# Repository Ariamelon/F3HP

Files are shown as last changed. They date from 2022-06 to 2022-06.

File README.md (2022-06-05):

# F3HP
A compact, class A amplifier with a schematic from [this](https://www.diyaudio.com/community/threads/3-transistor-hp-amplifier-with-low-dist.359267) thread.
This design uses mostly SMT components with some THT. It is designed to fit in [this](https://item.taobao.com/item.htm?id=543297256145) case. The 3D model and dimensions are included with the design files.

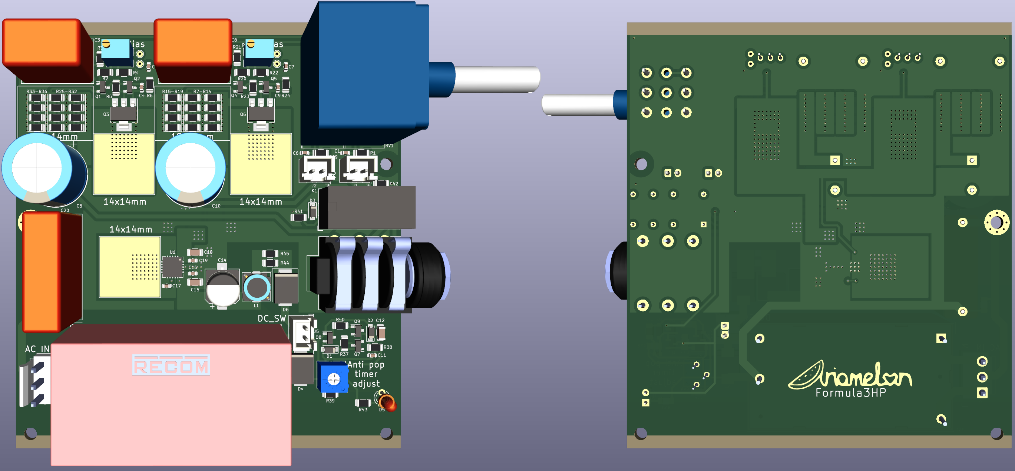
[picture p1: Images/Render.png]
Render

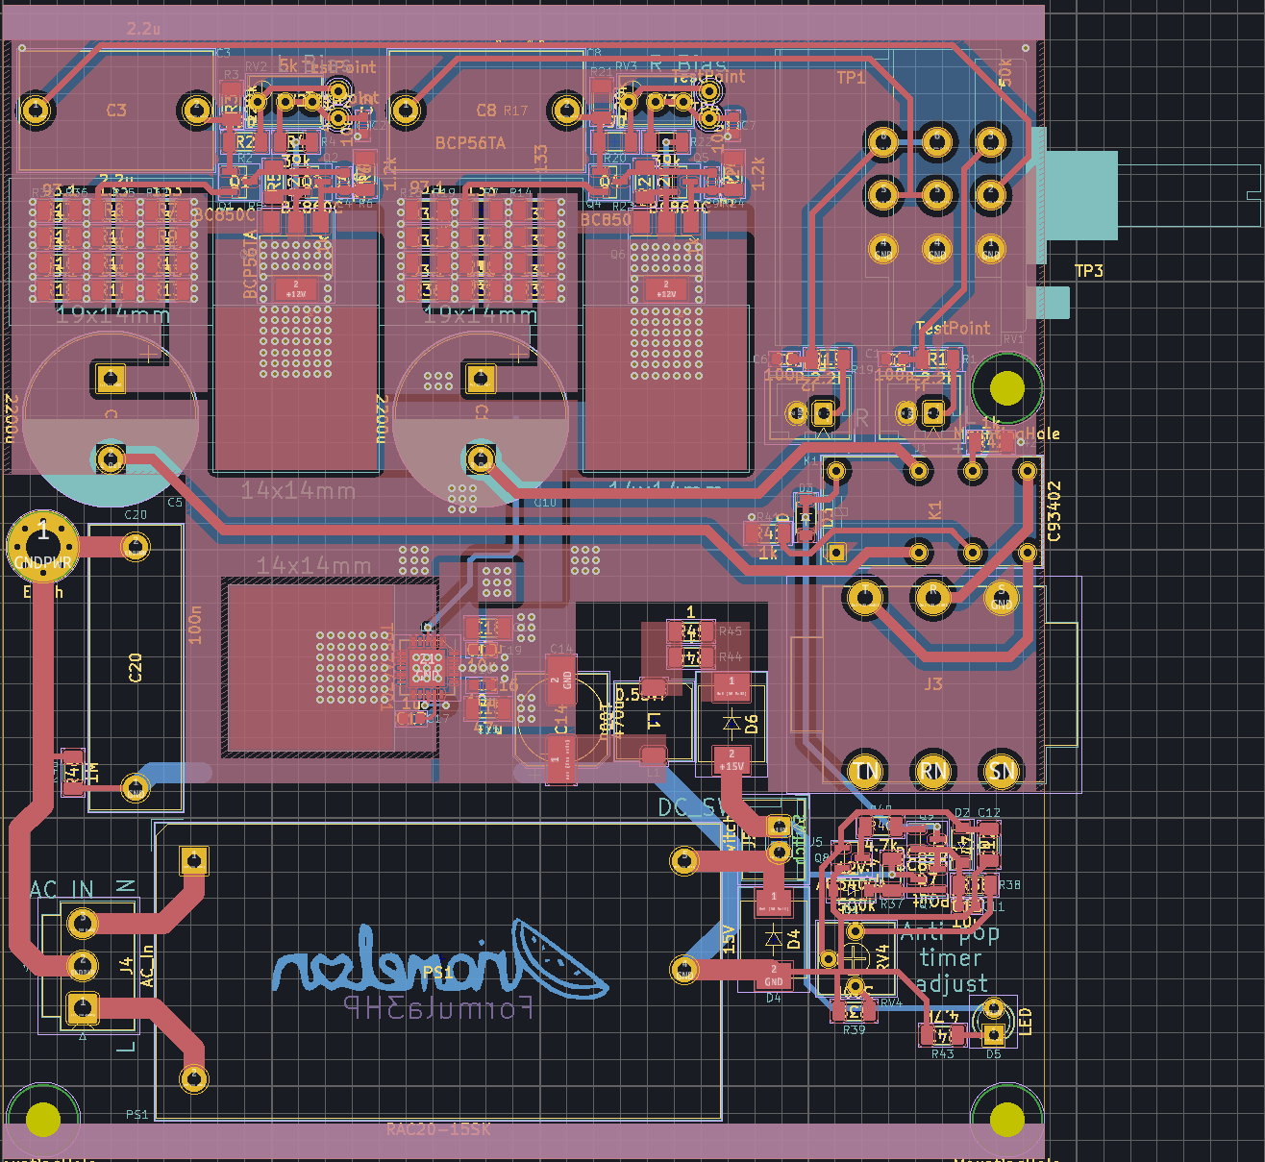
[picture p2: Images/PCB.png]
PCB

Schematic

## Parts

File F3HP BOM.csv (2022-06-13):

Qty | Reference(s) | Value | LCSC part number | Part number
2 | C1, C6 | 100p | C343033 | C1608NP01H101JT000N
5 | C2, C7, C11, C16, C19 | 10u | C2922482 | CL10A106MA8NRNC
2 | C3, C8 | 2.2u | C128507 | ECWFD2W225J
2 | C4, C9 | 330p | C343002 | C1608NP01H331JT000N
2 | C5, C10 | 2200u | C278533 | EEUFR1E222S
3 | C12, C15, C18 | 47u | C76659 | C3216X5R1E476MTJ00E
1 | C14 | 470u | C193277 | EEEFT1E471GP
1 | C17 | 1u | C15849 | CL10A105KB8NNNC
1 | C20 | 100n | C2926846 | PHE820ED6100MR06L2
1 | D1 | 12V | C550177 | BZT52-B12X
2 | D2, D3 | D | C81598 | 1N4148W
1 | D4 | 15V | C135138 | SMCJ15A-13-F
1 | D5 | LED | C2927624 | 204-10SUGC/S400-A5
1 | D6 | 0.55Vf | C134460 | B520C-13-F
1 | J1 | L_In | C158012 | B2B-XH-A
1 | J2 | R_In | C158012 | B2B-XH-A
1 | J3 | HPOut | C368502 | NMJ6HCD2
1 | J4 | AC_In | C160316 | B3P-VH(LF)(SN)
1 | J5 | Switch | C158012 | B2B-XH-A
1 | K1 | C93402 | C128021 | C93402
1 | L1 | 100u | C2045491 | SPM7054VT-101M-D
1 | PS1 | RAC20-15SK | N/A | RAC20-15SK
3 | Q1, Q4, Q7 | BC850C | C549507 | BC850C
3 | Q2, Q5, Q9 | BC860C | C549546 | BC860C
2 | Q3, Q6 | BCP56TA | C177012 | BCP56TA
1 | Q8 | AO3400A | C20917 | AO3400A
2 | R1, R19 | 2.2k |  | RT1206BRD072K2L
4 | R2, R20, R38, R39 | 392k |  | RT1206BRD07392KL
2 | R3, R21 | 120k | C136888 | RT1206BRD07120KL
2 | R4, R22 | 39.2k |  | RT1206DRD0739K2L
4 | R5, R23, R41, R42 | 1k | C706405 | RT1206BRD071KL
2 | R6, R24 | 1.4k | C870504 | RT1206BRD071K4L
16 | R7, R8, R9, R10, R11, R12, R13, R14, R25, R26, R27, R28, R29, R30, R31, R32 | 133 |  | RT1206DRD07133RL
8 | R15, R16, R17, R18, R33, R34, R35, R36 | 100 |  | RT1206DRD07100RL
3 | R37, R40, R43 | 4.7k | C706416 | RT1206BRD074K64L
2 | R44, R45 | 4.99 | C326584 | RT1206BRD074R99L
1 | R46 | 1M | C375528 | RT1206FRE071ML
1 | RV1 | 50k | C470507 | RK27112A00AK
2 | RV2, RV3 | 10k | C780232 | 3266W-1-104LF
1 | RV4 | 500k | C125021 | 3362P-1-504
1 | U1 | TPS7A4701 | C68214 | TPS7A4701
Additional
1 |  | IEC socket | N/A | DD11.0111.1111
1 |  | Fuse holder | N/A | 4301.1405
1 |  | Power switch | C1788492 | 100SP1T1B1M1QEH
1 |  | JST VH plug | C157899 | VHR-3N
3 |  | JST VH pins | C160349 | SVH-21T-P1.1
3 |  | JST XH plug | C144401 | XHP-2
6 |  | JST XH pins | C385122 | SXH-001T-P0.6N
1 |  | RCA black | N/A | NYS367-0
1 |  | RCA red | N/A | NYS367-2
1 |  | 30mm knob | N/A | N/A
1 |  | 200mA slow blow | C178874 | 0218.200MXP
4 |  | M3 x 6 |  | Normal screw
5 |  | M3 x 6 |  | Countersunk screw
3 |  | 14 x 14mm | C286220 | Heatsink
1 |  | 22 x 22mm | C286191 | Heatsink

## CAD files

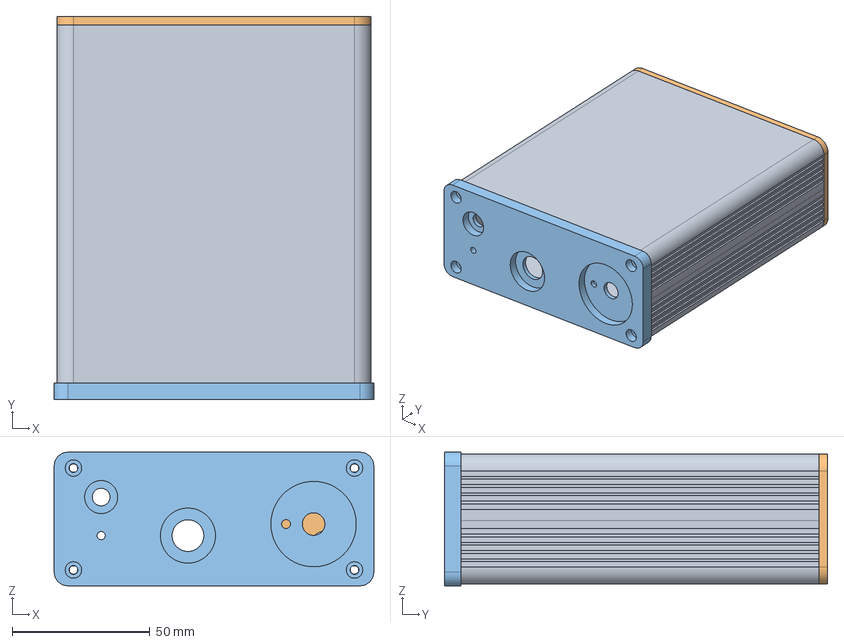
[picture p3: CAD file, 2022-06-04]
Case/Box.step
116.0 x 139.0 x 48.5 mm
Bottom
Top
Back
Front

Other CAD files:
Case/Dimensions.dxf

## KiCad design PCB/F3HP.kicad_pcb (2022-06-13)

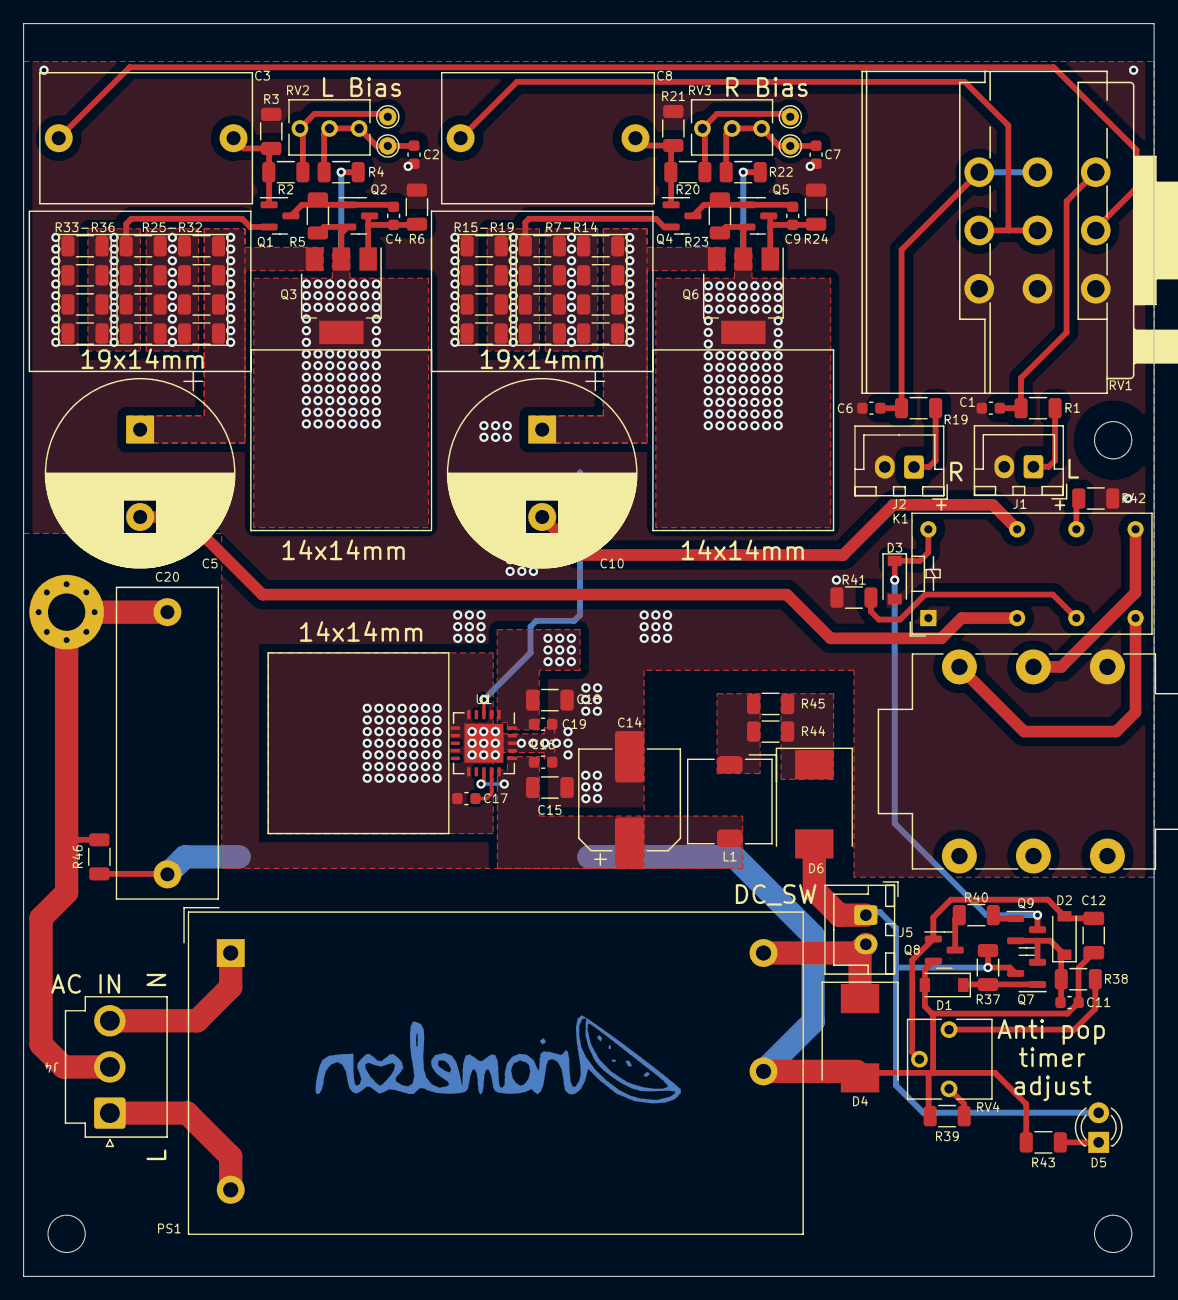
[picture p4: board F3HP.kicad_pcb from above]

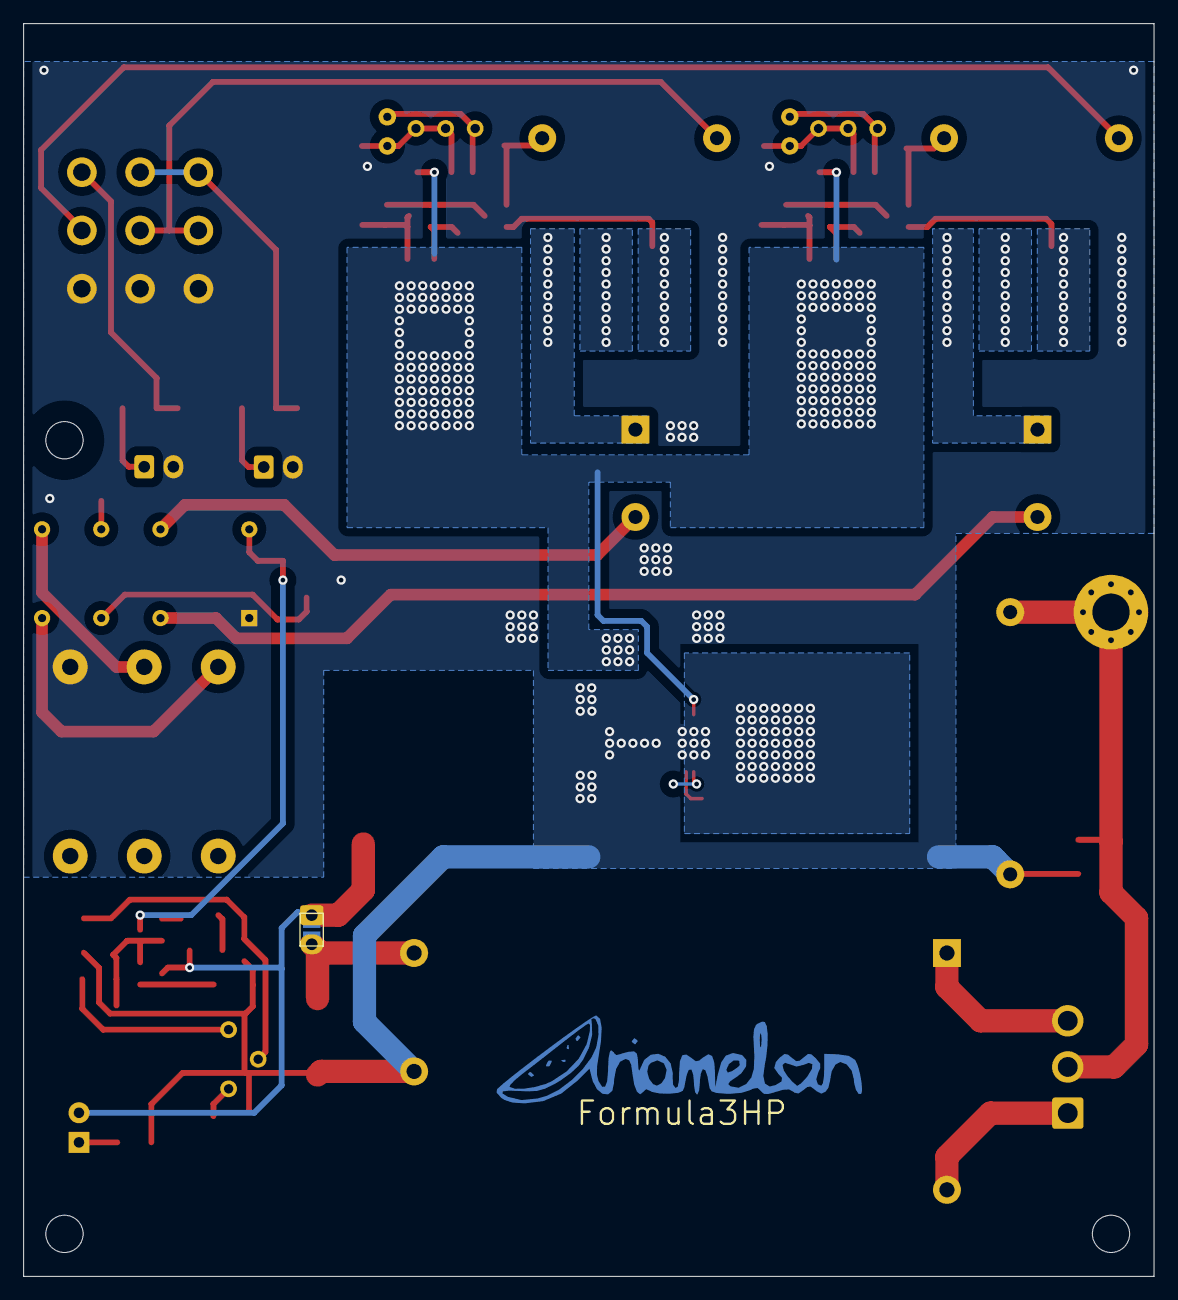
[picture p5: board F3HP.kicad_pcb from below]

Board: 2 copper layers, 97.0 x 107.5 mm, 103 parts (2 on the bottom side), 48 nets.

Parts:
A1: Art; Ariamelon_Logo_x3_CU
C1, C6: 100p; C_0603_1608Metric
C2, C7, C11, C16, C19: 10u; C_0603_1608Metric
C3, C8: 2.2u; C_Rect_L18.0mm_W11.0mm_P15.00mm_FKS3_FKP3
C4, C9: 330p; C_0603_1608Metric
C5, C10: 2200u; CP_Radial_D16.0mm_P7.50mm
C12, C15, C18: 47u; C_1206_3216Metric
C14: 470u; CP_Elec_8x10.5
C17: 1u; C_0603_1608Metric
C20: 100n; C_Rect_L26.5mm_W8.5mm_P22.50mm_MKS4
D1: 12V; D_SOD-123
D2, D3: D; D_SOD-123
D4: 15V; D_SMC
D5: LED; LED_D3.0mm
D6: 0.55Vf; D_SMC
H1, H2, H3: MountingHole; MountingHole_3.2mm_M3
H4: Earth; MountingHole_3.2mm_M3_Pad_Via
J1: L_In; JST_XH_B2B-XH-A_1x02_P2.50mm_Vertical
J2: R_In; JST_XH_B2B-XH-A_1x02_P2.50mm_Vertical
J3: HPOut; Jack_6.35mm_Neutrik_NMJ6HCD2_Horizontal
J4: AC_In; JST_VH_B3P-VH_1x03_P3.96mm_Vertical
J5: Switch; JST_XH_B2B-XH-A_1x02_P2.50mm_Vertical
JP1: Switch; SolderJumper-2_P1.3mm_Open_Pad1.0x1.5mm
K1: C93402; Relay_DPDT_Omron_G5V-2
L1: 100u; L_TDK_SLF7032
PS1: RAC20-15SK; Converter_ACDC_Recom_RAC20-xxSK_THT
Q1, Q4, Q7: BC850C; SOT-23
Q2, Q5, Q9: BC860C; SOT-23
Q3, Q6: BCP56TA; SOT-223-3_TabPin2
Q8: AO3400A; SOT-23
R1, R19: 2.2k; R_1206_3216Metric
R2, R20, R38, R39: 390k; R_1206_3216Metric
R3, R21: 120k; R_1206_3216Metric
R4, R22: 39k; R_1206_3216Metric
R5, R23: 820; R_1206_3216Metric
R6, R24: 1.2k; R_1206_3216Metric
R7, R8, R9, R10, R11, R12, R13, R14, R25, R26, R27, R28, R29, R30, R31, R32: 133; R_1206_3216Metric
R15, R16, R17, R18, R33, R34, R35, R36: 93.1; R_1206_3216Metric
R37, R40, R43: 4.7k; R_1206_3216Metric
R41, R42: 1k; R_1206_3216Metric
R44, R45: 1; R_1206_3216Metric
R46: 1M; R_1206_3216Metric
RV1: 50k; ALPS_RK27112
RV2, RV3: 5k; Potentiometer_Bourns_3266Y_Vertical
RV4: 500k; Potentiometer_Vishay_T73YP_Vertical
TP1, TP2, TP3, TP4: TestPoint; TestPoint_THTPad_D1.5mm_Drill0.7mm
U1: TPS7A4701; QFN-20-1EP_5x5mm_P0.65mm_EP3.35x3.35mm

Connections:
+12V: C18.1, C19.1, Q2.2 (E), Q3.2 (C), Q5.2 (E), Q6.2 (C), R4.2, R5.1, R22.2, R23.1, U1.1 (OUT), U1.3 (SENSE/FB), U1.20 (OUT)
+15V: D5.2 (A), D6.2 (A), J5.1, JP1.1, Q7.3 (C), R37.1
GND: C1.1, C2.2, C6.1, C7.2, C11.2, C12.2, C14.2, C15.2, C16.2, C17.2, C18.2, C19.2, C20.1, D1.2 (A), D3.2 (A), D4.2 (A), J1.2, J2.2, J3.S, K1.1, PS1.4 (-Vout), Q8.2 (S), R3.2, R6.2, R15.2, R16.2, R17.2, R18.2, R21.2, R24.2, R33.2, R34.2, R35.2, R36.2, R39.2, R41.1, R42.1, R43.2, R46.1, RV1.1, RV1.4, U1.2 (NC), U1.5 (6P4V1), U1.6 (3P2V), U1.7 (GND), U1.9 (0P8V), U1.11 (0P2V), U1.17 (NC), U1.18 (NC), U1.19 (NC), U1.21 (GND)
GNDPWR: C20.2, H4.1, J4.2, R46.2
L_Out: C5.2, K1.4
unnamed: C1.2, R1.1, RV1.3
unnamed: C2.1, R4.1, RV2.2, RV2.3, TP1.1
unnamed: C3.1, RV1.2
unnamed: C3.2, Q1.1 (B), R2.2, R3.1
unnamed: C4.1, Q2.3 (C), Q3.1 (B), R6.1
unnamed: C4.2, Q1.3 (C), Q2.1 (B), R5.2
unnamed: C5.1, Q3.3 (E), R7.1, R9.1, R11.1, R13.1
unnamed: C6.2, R19.1, RV1.6
unnamed: C7.1, R22.1, RV3.2, RV3.3, TP3.1
unnamed: C8.1, RV1.5
unnamed: C8.2, Q4.1 (B), R20.2, R21.1
unnamed: C9.1, Q5.3 (C), Q6.1 (B), R24.1
unnamed: C9.2, Q4.3 (C), Q5.1 (B), R23.2
unnamed: C10.1, Q6.3 (E), R25.1, R27.1, R29.1, R31.1
unnamed: C11.1, D2.1 (K), Q7.2 (E), Q9.2 (E), R38.1
unnamed: C12.1, D2.2 (A), Q8.1 (G), RV4.2
unnamed: C14.1, C15.1, C16.1, L1.2, U1.13 (EN), U1.15 (IN), U1.16 (IN)
unnamed: C17.1, U1.14 (NR)
unnamed: D1.1 (K), Q7.1 (B), R37.2
unnamed: D3.1 (K), K1.16, Q9.3 (C)
unnamed: D4.1 (K), J5.2, JP1.2, PS1.5 (+Vout)
unnamed: D5.1 (K), R43.1
unnamed: D6.1 (K), R44.1, R45.1
unnamed: J1.1, R1.2
unnamed: J2.1, R19.2
unnamed: J3.R, K1.9
unnamed: J3.T, K1.8
unnamed: J4.1, PS1.2 (AC(L))
unnamed: J4.3, PS1.1 (AC(N))
unnamed: K1.6, R41.2
unnamed: K1.11, R42.2
unnamed: L1.1, R44.2, R45.2
unnamed: Q1.2 (E), R8.2, R10.2, R12.2, R14.2, R15.1, R16.1, R17.1, R18.1
unnamed: Q4.2 (E), R26.2, R28.2, R30.2, R32.2, R33.1, R34.1, R35.1, R36.1
unnamed: Q8.3 (D), R40.1
unnamed: Q9.1 (B), R40.2
unnamed: R2.1, RV2.1, TP2.1
unnamed: R7.2, R8.1, R9.2, R10.1, R11.2, R12.1, R13.2, R14.1
unnamed: R20.1, RV3.1, TP4.1
unnamed: R25.2, R26.1, R27.2, R28.1, R29.2, R30.1, R31.2, R32.1
unnamed: R38.2, RV4.1
unnamed: R39.1, RV4.3
R_Out: C10.2, K1.13

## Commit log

2022-06-05 Better layout, better heatsinking
    [BOM.csv, F3HP.kicad_pcb, F3HP.kicad_sch]
2022-06-07 Updated component values and BOM
    [BOM.csv, F3HP.kicad_pcb, F3HP.kicad_sch]
2022-06-08 Swapped to TPS7A4701 LDO, better performance and less complicated PCB required
    [BOM.csv, F3HP.kicad_pcb, F3HP.kicad_sch]
2022-06-08 Errors fixed
    [F3HP.kicad_pcb]
2022-06-09 Added back LC filter after ACDC converter
    [BOM.csv, F3HP.kicad_pcb, F3HP.kicad_sch]
2022-06-09 Added Alps RK163 support
    [F3HP.kicad_pcb, F3HP.kicad_sch]
2022-06-13 Changed resistors to 1206 to lower distortion
    [BOM.csv, F3HP BOM.csv, F3HP.kicad_pcb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]
